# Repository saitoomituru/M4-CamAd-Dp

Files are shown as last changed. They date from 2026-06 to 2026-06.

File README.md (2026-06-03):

# M4ロッド → 1/4インチ スタジオアダプター

**Dr. SILICON / ZeroRoomLab**

中華製タブレット吸盤アーム（M4メスロッドタイプ）を、スタジオ照明・マジックアームで標準的な1/4-20オスダボに変換する3Dプリント製アダプターです。

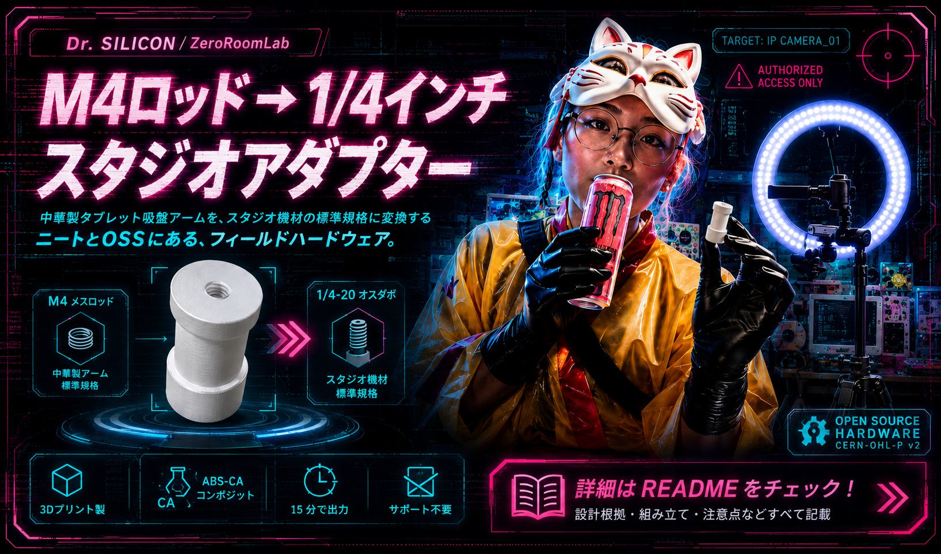
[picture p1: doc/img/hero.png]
ヒービジュアル


---

## 概要

中華製タブレット吸盤アームのロッドソケットはM4メス規格です。スタジオ機材（リングライト・ボールヘッドブロック・アイスライトマウント等）は1/4-20オスダボを前提に設計されています。このアダプター1個でその差を埋めます。

CA複合化後処理により、実用スタジオ荷重に耐える剛性を実現しています。

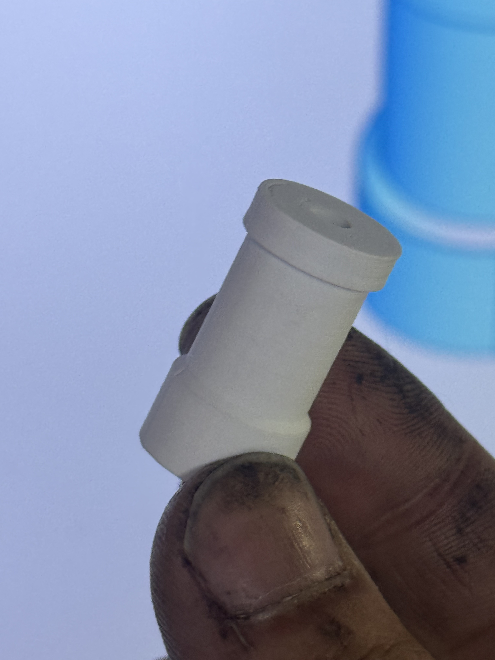
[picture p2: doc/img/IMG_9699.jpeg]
アダプター単体


- プリント時間：約15分
- モデリング時間：約5分
- フィラメントコスト：¥50以下

---

## 対応アーム

**M4メスロッドソケット**を持つタブレット・iPad用吸盤アーム全般（Amazon JP・AliExpress流通の中華製品の大半が該当）。

出力側：**1/4-20オスダボ**（スタジオ標準コールドシュー・マジックアーム・ライトスタンドソケット）。

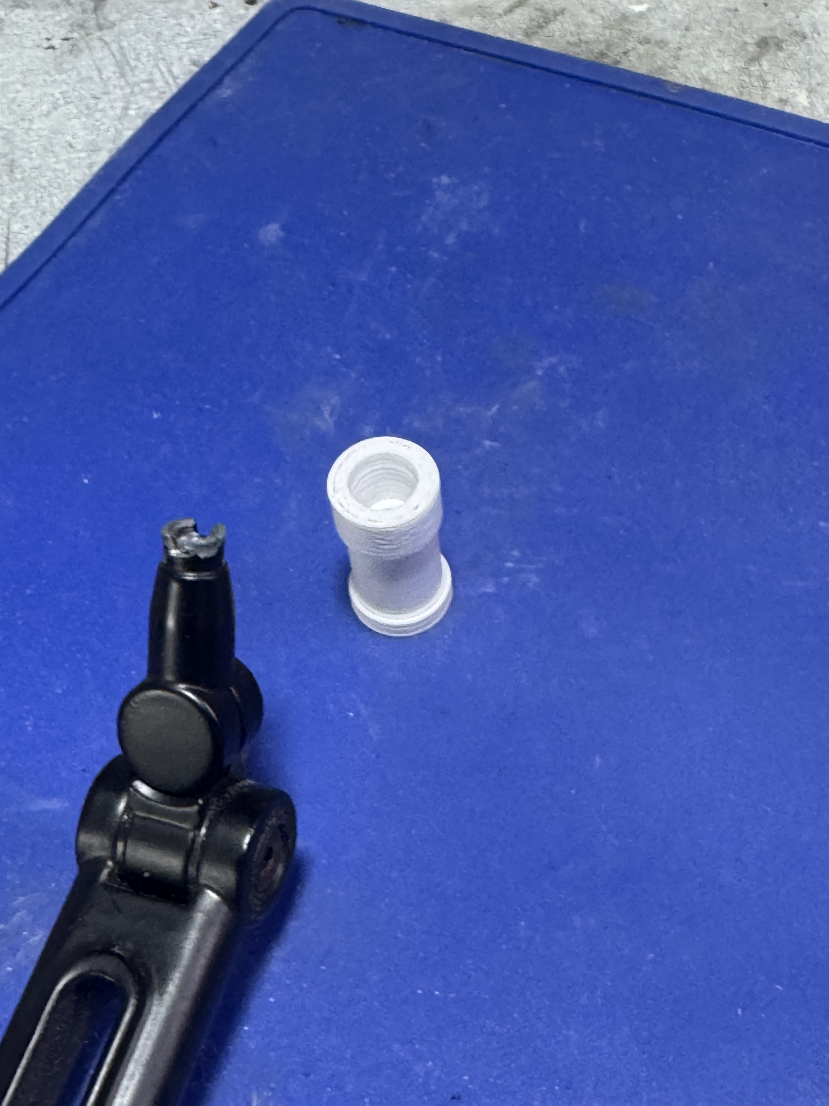
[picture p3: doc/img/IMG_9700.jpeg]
アダプターとアーム


---

## ファイル構成

```
/
├── stage/
│   └── stl/
│       └── オスダボ-BodyChamfer001.stl
├── bild/
│   └── オスダボ.FCStd              (FreeCAD)
├── doc/
│   └── img/
│       ├── hero.png
│       ├── IMG_9699.jpeg           # アダプター単体
│       ├── IMG_9700.jpeg           # アームとの組み合わせ
│       ├── IMG_9701.jpeg           # 後処理材料
│       ├── IMG_9702.jpeg           # ボルト挿入工程
│       ├── IMG_9703.jpeg           # アーム取り付け
│       └── IMG_9704.jpeg           # 完成使用例
└── README.md
```

---

## プリント設定

| パラメータ | 値 |
|---|-----|
| 素材 | **ABS必須**（理由は後述） |
| ノズル温度 | 248 °C |
| シェル数 | 3層 |
| 底面層数 | 4層 |
| インフィル | 45 % |
| サポート | **不要** |
| プリント方向 | **逆Z**（M4ソケット面をベッドに置く） |

### ABSが必須な理由

PLAはシアノアクリレートの毛細管浸透を受け付けません。後述のCA複合化処理が剛性の主要な供給源であるため、PLAで出力した場合はせん断強度が大幅に低下します。PETGは不十分です。**ABS一択**です。

### 逆Z方向プリントの理由

- M4ボルト座面（ワッシャ当たり面）をベッドに置くことで、荷重集中点に最密・最平滑な層が来る
- 積層方向が主引っ張り軸と直交するため、引き抜き方向の層間剥離が発生しない
- オーバーハング側のテーパー・面取り形状がこの方向で自己支持角に収まるため、サポート材ゼロ・内径面も荒れない

---

## 後処理：ABS–CAコンポジット処理

この工程により、多孔質ABSプリントをハイブリッド複合材に変換します。単体ABSより大幅に高い剛性を得ながら、ABSの「折れる前にしなる」特性を残します。

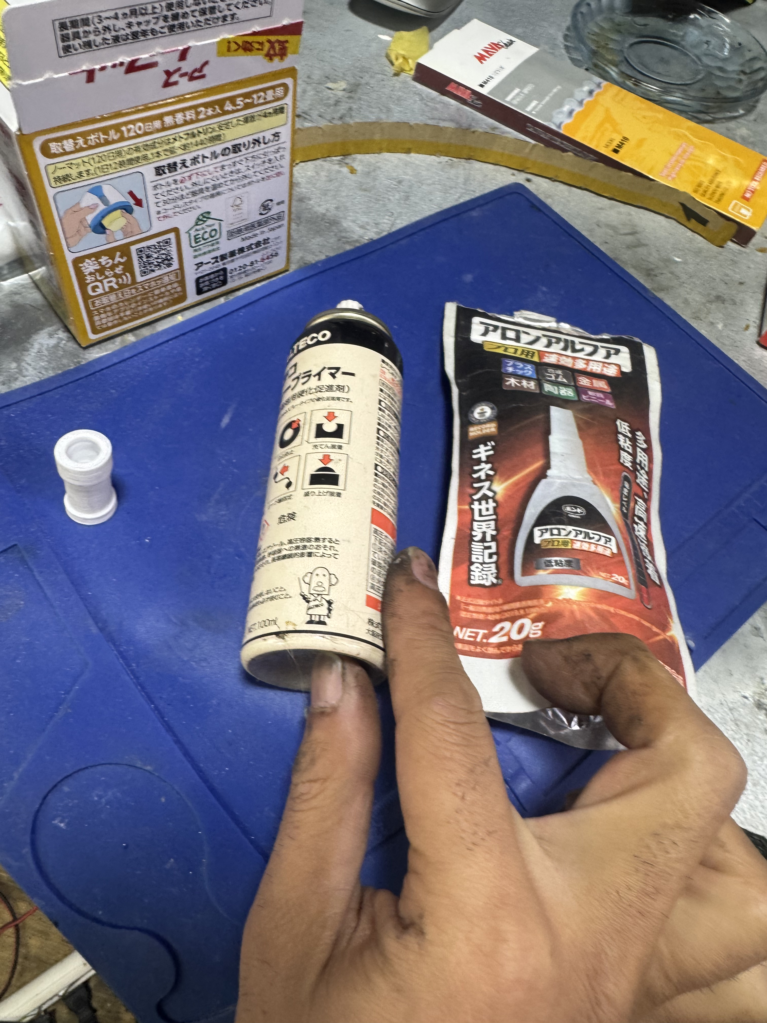
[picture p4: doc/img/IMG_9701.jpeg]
後処理材料（アロンアルファ低粘度＋CAプライマー）


1. **低粘度シアノアクリレート**（例：アロンアルファ プロ用 低粘度）を全露出面から多めに流し込む。毛細管現象でインフィル空隙に浸透させる。
2. **M4ボルトを挿入**し、CA未硬化のうちに着座させる。

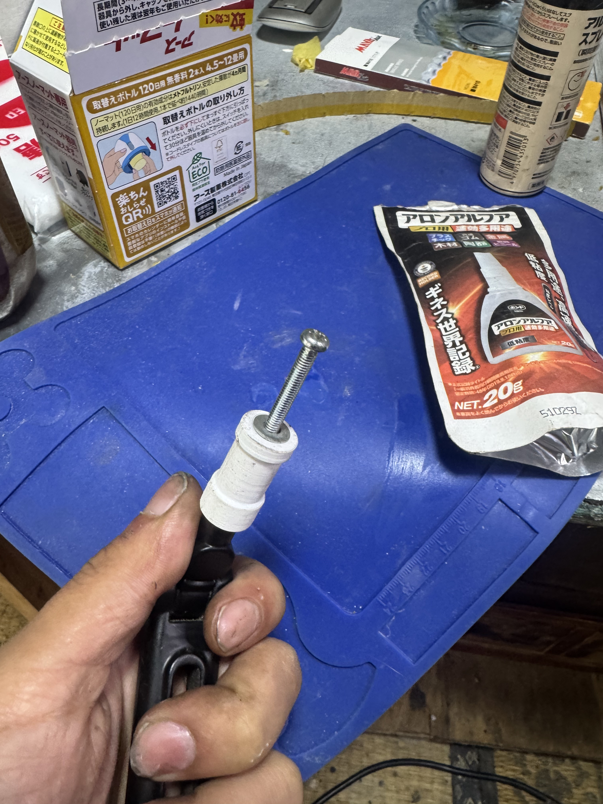
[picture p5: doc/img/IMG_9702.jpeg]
M4ボルト挿入
   

3. **CAプライマー（硬化促進剤）**を部品の横からスプレーし、内部CAを同時硬化させる。過剰噴霧不要——横から短く吹くだけで十分。
4. 完全硬化後に組み付ける。

結果：ABSマトリクス＋CA充填＝XYせん断をコンポジット壁で受け、Z軸はM4ボルト＋ワッシャで機械的に拘束する構成（後述）。

---

## 組み付け

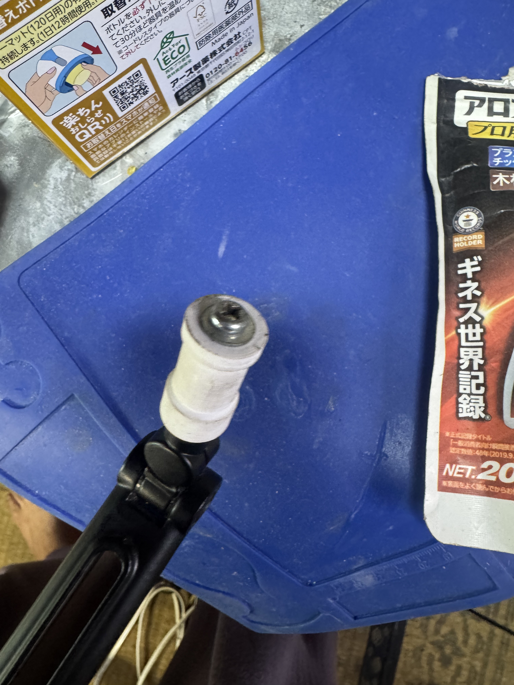
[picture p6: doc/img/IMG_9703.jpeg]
アームへの取り付け


**別途用意するもの：**

- M4ボルト（相手アームのソケット深さに合わせた長さ）
- M4ワッシャ（素材選定は下記の電食注意事項を参照）

**荷重分担：**

- **Z軸（引き抜き方向）：** M4ボルト＋ワッシャによる機械拘束のみで担当。CAコンポジットはこの荷重を負わない。剥離モードを設計で排除している。
- **XY軸（傾き・せん断方向）：** アダプター本体のCAコンポジット壁と1/4-20ダボの嵌合長で担当。

---

## ⚠️ ボルト・ワッシャの素材選定——電食（ガルバニック腐食）について

異種金属接触部に水分が入ると電食が進行します。相手素材に合わせて選定してください。

| アーム素材 | ボルト・ワッシャ指定 |
|---|---|
| **アルミ**（中華アームの大半はアルミダイキャスト） | **ステンレス**——電位差小さく問題なし |
| **鋳鉄・鉄系**アーム | **ユニクロ（亜鉛メッキ）**——ステンレス×鉄は電位差が大きく、湿潤環境で鉄側が腐食する |

判別方法：磁石で確認。アルミは非磁性→ステンレス。磁性あり→ユニクロ。

ワッシャもボルトと同素材で揃えること。

---

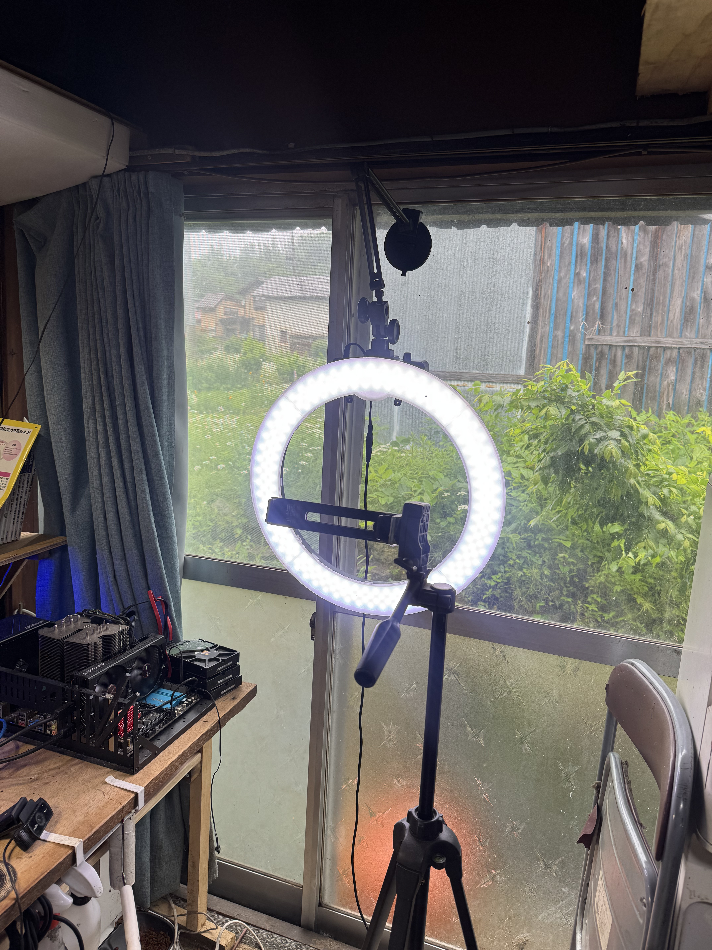
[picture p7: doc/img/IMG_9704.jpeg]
リングライト装着・完成使用例


---

## 設計メモ

全径変化部にテーパーを設けることで、逆Z方向プリント時にすべてのオーバーハング面が自己支持角に収まります。水平オーバーハングは存在しません。これにより内径面が荒れず、CA浸透経路が均質になります。

インフィル45%は意図的な数値です。クランプ荷重に耐えるだけの密度を保ちながら、CAが断面全体に浸透できる空隙を確保するバランスです。高すぎるとCA複合効果が失われ、低すぎるとABSマトリクスの構造寄与が不足します。

---

## ライセンス

**CERN Open Hardware Licence Version 2 – Permissive（CERN-OHL-P v2）**

本ハードウェア設計は自由に使用・研究・改変・再配布できます。帰属表示の維持と改変箇所の明示を条件とします。

ライセンス全文：https://ohwr.org/cern_ohl_p_v2.txt

---

## 作者

**Dr. SILICON** — ZeroRoomLab  
山形県高畠町  
https://github.com/saitoomituru

*Dr. SILICON OSHシリーズ——設計根拠を明文化した実用フィールドハードウェア*

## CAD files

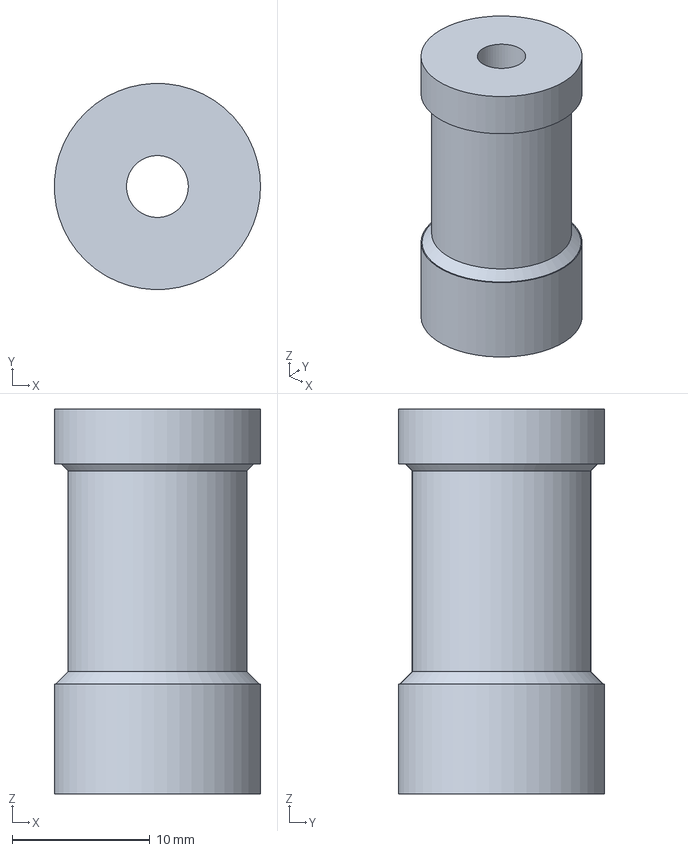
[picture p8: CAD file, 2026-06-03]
bild/オスダボ.FCStd
15.0 x 15.0 x 28.0 mm

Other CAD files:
stage/stl/オスダボ-BodyChamfer001.stl

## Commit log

2026-06-03 初回コミット
    [オスダボ-BodyChamfer001.stl, オスダボ.FCStd]
2026-06-03 ドキュメント整理
